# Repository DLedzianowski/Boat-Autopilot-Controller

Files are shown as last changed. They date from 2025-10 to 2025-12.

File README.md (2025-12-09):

# Boat-Autopilot-Controller
PCB for a small boat autopilot system. Collects sensor data and drives actuators to maintain set course/position.

scr2

## Main Features
- STM32WB55 – main MCU with BLE
- MAX-M10S – GNSS positioning
- TMC2208 – stepper motor driver
- LIS3MDL – magnetometer (compass)
- AS5600 connector – absolute encoder input
- DC motor controller connector

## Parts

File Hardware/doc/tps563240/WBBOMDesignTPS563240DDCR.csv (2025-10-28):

Part | Manufacturer | Part Number | Quantity | Price ($) | Footprint (mm²) | Description
Rfbt | Vishay-Dale | CRCW040245K3FKED | 1 | 0.01 | 3 | Resistance: 45.3 kΩ Tolerance: 1.0% Power: 63 mW
Rfbb | Yageo | RC0201FR-0710KL | 1 | 0.01 | 2.08 | Resistance: 10 kΩ Tolerance: 1.0% Power: 50 mW
U1 | Texas Instruments | TPS563240DDCR | 1 | 0.23 | 10.47
L1 | Coilcraft | SER1590-152MLB | 1 | 1.12 | 324.12 | L: 1.5 µH DCR: 1.1 mΩ IDC: 19 A
Cin | MuRata | GRM21BR61E106MA73L | 2 | 0.04 | 6.75 | Cap: 10 µF Total Derated Cap: 2.8 µF VDC: 25 V ESR: 4 mΩ Package: 0805
Cboot | Taiyo Yuden | EMK107B7104KA-T | 1 | 0.01 | 4.68 | Cap: 100 nF Total Derated Cap: 100 nF VDC: 16 V ESR: 1 mΩ Package: 0603
Cout | MuRata | GRM188R60J226MEA0D | 3 | 0.04 | 4.68 | Cap: 22 µF Total Derated Cap: 24 µF VDC: 6.3 V ESR: 1 mΩ Package: 0603
Cinx | Yageo | CC0805KRX7R9BB104 | 1 | 0.02 | 6.75 | Cap: 100 nF Total Derated Cap: 98 nF VDC: 50 V ESR: 1 mΩ Package: 0805

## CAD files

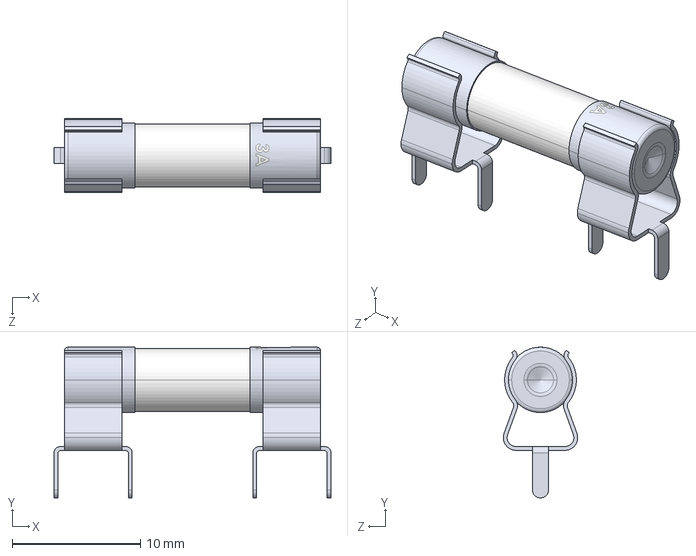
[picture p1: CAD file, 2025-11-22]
Hardware/kicad/PUEiE_pcb/models/Fuse Holder.step
21.6 x 11.8 x 5.80 mm
Fuse Clip x 2
3A Fuse

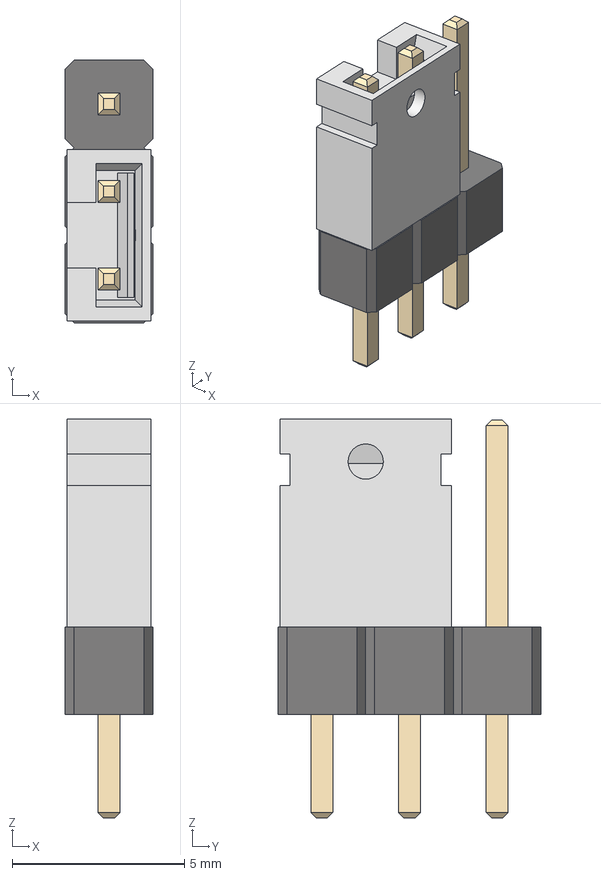
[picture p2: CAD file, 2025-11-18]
Hardware/kicad/PUEiE_pcb/models/pin_jumper_2.54mm.step
2.54 x 7.62 x 11.6 mm
PinHeader_1x03_P254mm_Vertical
26m5017_142270-1

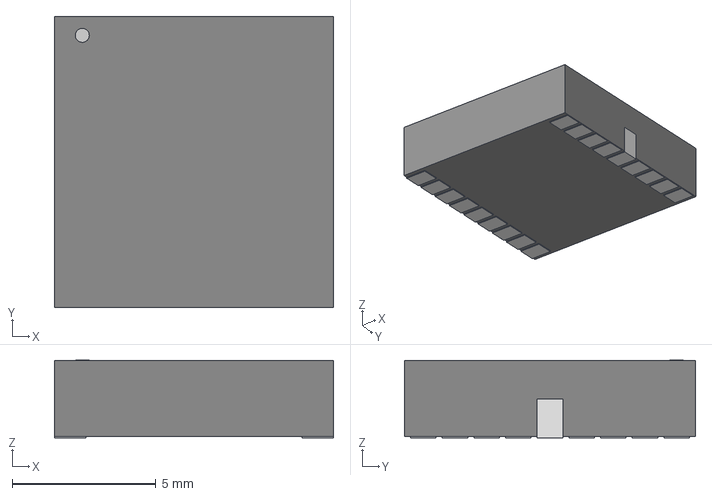
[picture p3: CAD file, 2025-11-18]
Hardware/kicad/PUEiE_pcb/models/MOD18_MAX-M10M_UBL.step
9.70 x 10.1 x 2.69 mm

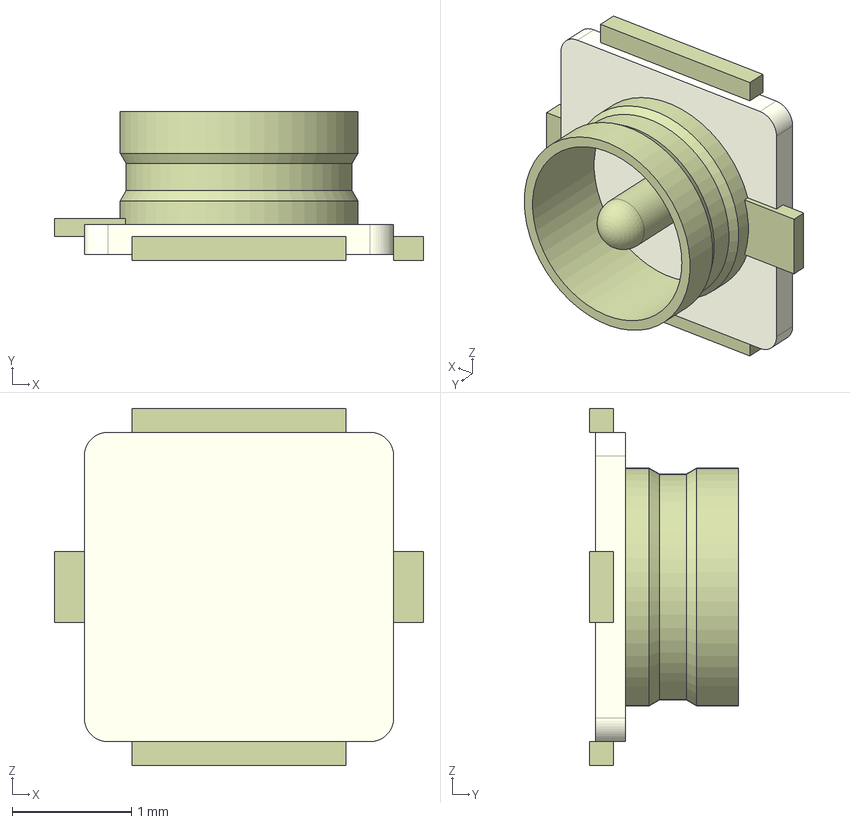
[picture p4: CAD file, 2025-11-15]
Hardware/kicad/PUEiE_pcb/models/ipex_connector.step
3.10 x 1.25 x 3.00 mm

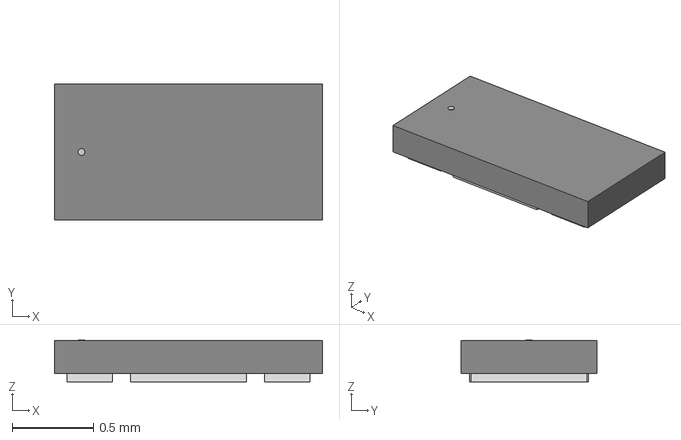
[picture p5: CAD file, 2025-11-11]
Hardware/kicad/PUEiE_pcb/models/DLF162500LT-5028A1.step
1.65 x 0.838 x 0.257 mm

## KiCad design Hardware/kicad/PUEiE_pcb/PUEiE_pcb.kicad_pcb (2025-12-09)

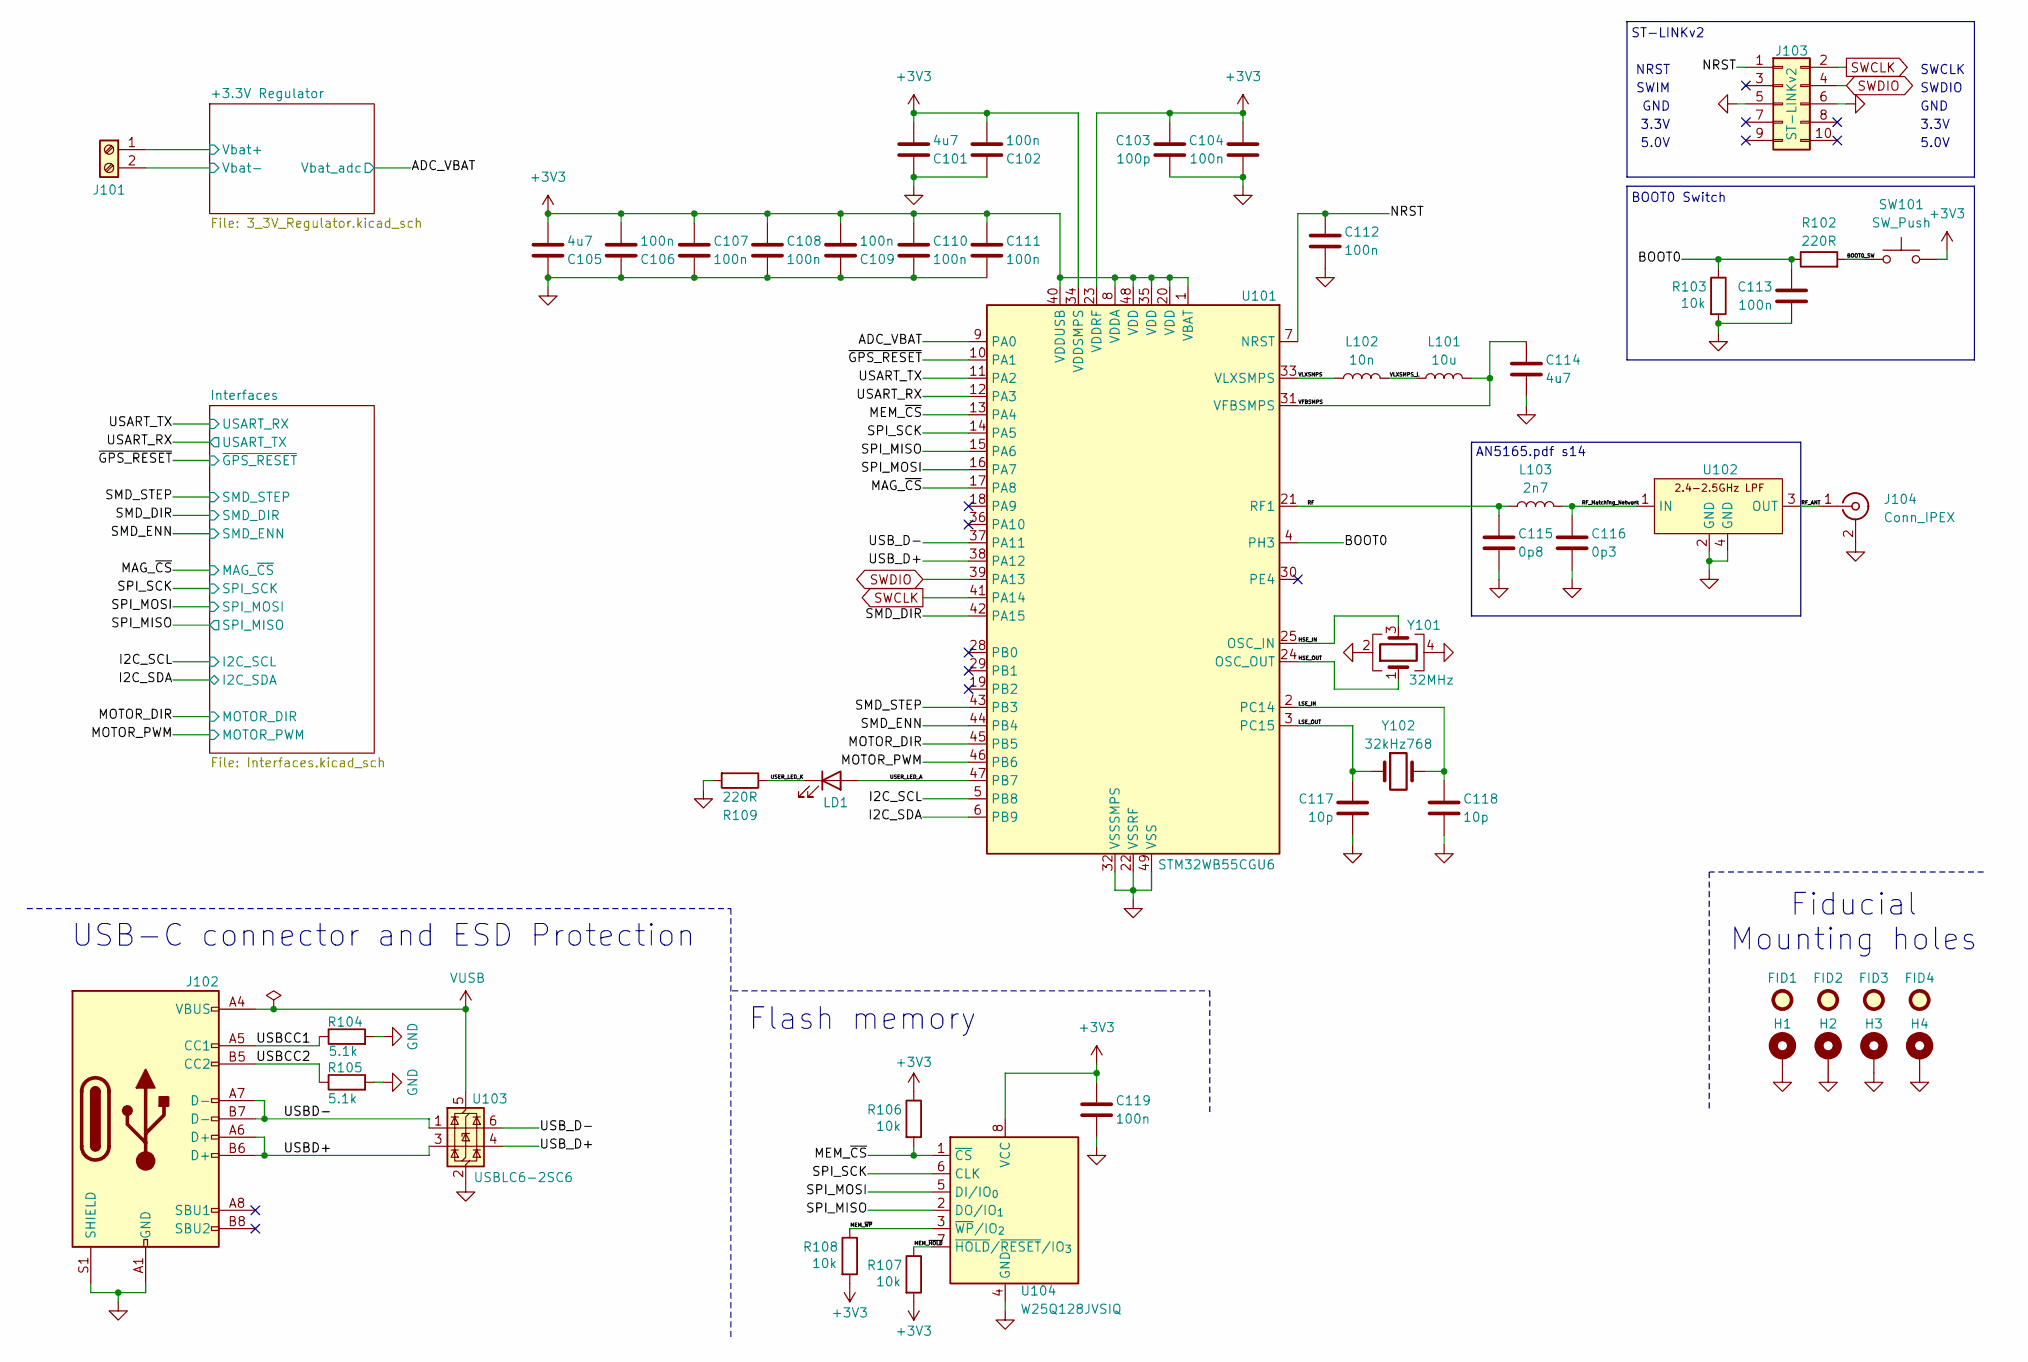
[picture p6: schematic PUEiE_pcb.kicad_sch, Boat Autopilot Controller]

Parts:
C101, C105, C114: 4u7; C_0805_2012Metric; MFR Part CL21A475KAQNNNE
C102, C104, C106, C107, C108, C109, C110, C111, C112, C113, C119: 100n; C_0805_2012Metric; MFR Part CL21B104KCFNNNE
C103: 100p; C_0805_2012Metric; MFR Part CL21C101JBANNNC
C115: 0p8; C_0402_1005Metric; MFR Part GRM1555C1HR80BA01D
C116: 0p3; C_0402_1005Metric; MFR Part GRM1555C1HR30WA01D
C117, C118: 10p; C_0603_1608Metric; MFR Part CL10C100JB8NNNC
FID1, FID2, FID3, FID4: Fiducial; Fiducial_1mm_Mask2mm
H1, H2, H3, H4: MountingHole_Pad; MountingHole_3.2mm_M3_Pad
J101: Screw_Terminal_01x02; TerminalBlock_Phoenix_PT-1,5-2-3.5-H_1x02_P3.50mm_Horizontal; MFR Part PRT-08084
J102: USB_C_Receptacle_USB2.0_16P; USB_C_Receptacle_GCT_USB4105-xx-A_16P_TopMnt_Horizontal; MFR Part USB4105-GF-A-060
J103: ST-LINKv2; PinHeader_2x05_P2.54mm_Vertical; MFR Part HX JN1.27-2x5P ZZ H4.9
J104: Conn_IPEX; IPEX Male; MFR Part BWIPX-1-001E
L101: 10u; L_0603_1608Metric; MFR Part SDFL1608S100KTF
L102: 10n; L_0402_1005Metric; MFR Part LQG15WZ10NJ02D
L103: 2n7; L_0402_1005Metric; MFR Part LQG15HS2N7S02D
LD1: LD1; LED_0805_2012Metric; MFR Part NCD0805B2
R102, R109: 220R; R_0805_2012Metric; MFR Part 0805W8F2200T5E
R103, R106, R107, R108: 10k; R_0805_2012Metric; MFR Part 0805W8F1002T5E
R104, R105: 5.1k; R_0805_2012Metric; MFR Part 0805W8F5101T5E
SW101: SW_Push; SW_2pin_5.5x2.0mm; MFR Part TS-1088-AR02016
U101: STM32WB55CGU6; QFN-48-1EP_7x7mm_P0.5mm_EP5.6x5.6mm_ThermalVias; MFR Part STM32WB55CGU6
U102: DLF162500LT-5028A1; MFR Part DLF162500LT-5028A1
U103: USBLC6-2SC6; SOT-23-6; MFR Part USBLC6-2SC6
U104: W25Q128JVSIQ; SOIC-8_5.3x5.3mm_P1.27mm; MFR Part W25Q128JVSIQ
Y101: 32MHz; Crystal_SMD_2016-4Pin_2.0x1.6mm; MFR Part NX2016SA-32MHZ-STD-CZS-5
Y102: 32kHz768; Crystal_SMD_2012-2Pin_2.0x1.2mm; MFR Part NX2012SA 32.768KHZ STD-MUB-1

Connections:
+3V3: C101.2, C102.2, C103.1, C104.1, C105.2, C106.2, C107.1, C108.1, C109.2, C110.1, C111.1, C119.1, R106.1, R107.2, R108.2, SW101.2, U101.1 (VBAT), U101.8 (VDDA), U101.20 (VDD), U101.23 (VDDRF), U101.34 (VDDSMPS), U101.35 (VDD), U101.40 (VDDUSB), U101.48 (VDD), U104.8 (VCC); also elsewhere on the board
/+3.3V Regulator/Vbat+: J101.1; also elsewhere on the board
/ADC_VBAT: U101.9 (PA0); also elsewhere on the board
/BOOT0: C113.1, R102.1, R103.1, U101.4 (PH3)
/BOOT0_SW: R102.2, SW101.1
/HSE_IN: U101.25 (OSC_IN), Y101.3
/HSE_OUT: U101.24 (OSC_OUT), Y101.1
/I2C_SCL: U101.5 (PB8); also elsewhere on the board
/I2C_SDA: U101.6 (PB9); also elsewhere on the board
/LSE_IN: C118.1, U101.2 (PC14), Y102.2
/LSE_OUT: C117.1, U101.3 (PC15), Y102.1
/MAG_~CS: U101.17 (PA8); also elsewhere on the board
/MEM_~CS: R106.2, U101.13 (PA4), U104.1 (~CS)
/MEM_~HOLD: R107.1, U104.7 (~HOLD/~RESET/IO_{3})
/MEM_~WP: R108.1, U104.3 (~WP/IO_{2})
/MOTOR_DIR: U101.45 (PB5); also elsewhere on the board
/MOTOR_PWM: U101.46 (PB6); also elsewhere on the board
/NRST: C112.1, J103.1, U101.7 (NRST)
/RF: C115.1, L103.1, U101.21 (RF1)
/RF_ANT: J104.1 (In), U102.3 (OUT)
/RF_Matching_Network: C116.1, L103.2, U102.1 (IN)
/SMD_DIR: U101.42 (PA15); also elsewhere on the board
/SMD_ENN: U101.44 (PB4); also elsewhere on the board
/SMD_STEP: U101.43 (PB3); also elsewhere on the board
/SPI_MISO: U101.15 (PA6), U104.2 (DO/IO_{1}); also elsewhere on the board
/SPI_MOSI: U101.16 (PA7), U104.5 (DI/IO_{0}); also elsewhere on the board
/SPI_SCK: U101.14 (PA5), U104.6 (CLK); also elsewhere on the board
/USART_RX: U101.12 (PA3); also elsewhere on the board
/USART_TX: U101.11 (PA2); also elsewhere on the board
/USBCC1: J102.A5 (CC1), R104.1
/USBCC2: J102.B5 (CC2), R105.1
/USBD+: J102.A6 (D+), J102.B6 (D+), U103.3 (I/O2)
/USBD-: J102.A7 (D-), J102.B7 (D-), U103.1 (I/O1)
/USB_D+: U101.38 (PA12), U103.4 (I/O2)
/USB_D-: U101.37 (PA11), U103.6 (I/O1)
/USER_LED_A: LD1.2 (A), U101.47 (PB7)
/USER_LED_K: LD1.1 (K), R109.1
/VFBSMPS: C114.1, L101.2, U101.31 (VFBSMPS)
/VLXSMPS: L102.1, U101.33 (VLXSMPS)
/VLXSMPS_L: L101.1, L102.2
/~GPS_RESET: U101.10 (PA1); also elsewhere on the board
GND: C101.1, C102.1, C103.2, C104.2, C105.1, C106.1, C107.2, C108.2, C109.1, C110.2, C111.2, C112.2, C113.2, C114.2, C115.2, C116.2, C117.2, C118.2, C119.2, H1.1, H2.1, H3.1, H4.1, J101.2, J102.A1 (GND), J102.A12 (GND), J102.B1 (GND), J102.B12 (GND), J102.S1 (SHIELD), J103.5, J103.6, J104.2 (Ext), R103.2, R104.2, R105.2, R109.2, U101.22 (VSSRF), U101.32 (VSSSMPS), U101.49 (VSS), U102.2 (GND), U102.4 (GND), U103.2 (GND), U104.4 (GND), Y101.2, Y101.4; also elsewhere on the board
SWCLK: J103.2, U101.41 (PA14)
SWDIO: J103.4, U101.39 (PA13)
VUSB: J102.A4 (VBUS), J102.A9 (VBUS), J102.B4 (VBUS), J102.B9 (VBUS), U103.5 (VBUS); also elsewhere on the board

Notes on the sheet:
AN5165.pdf s14
5.0V
BOOT0 Switch
GND
USB-C connector and ESD Protection
3.3V
SWDIO
SWCLK
ST-LINKv2
Fiducial Mounting holes
SWIM
Flash memory
NRST

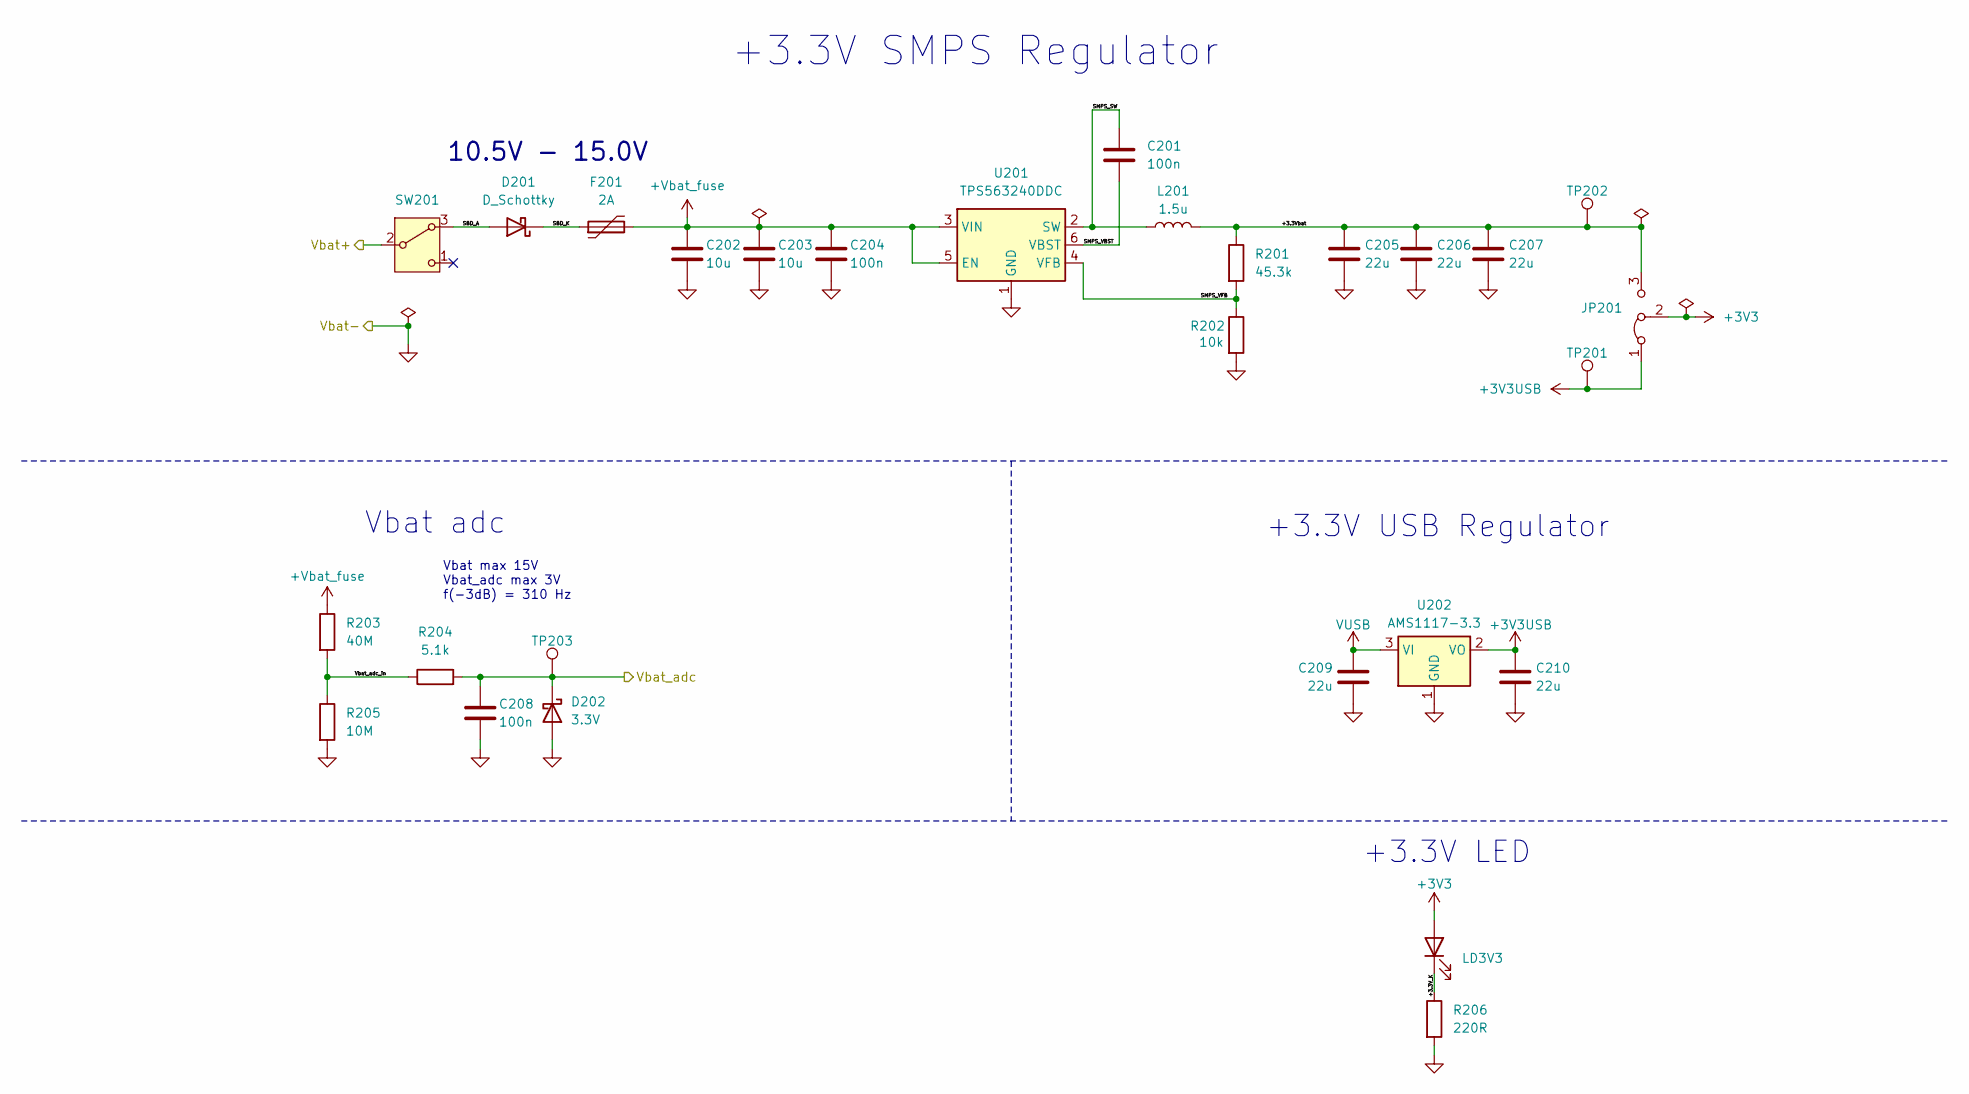
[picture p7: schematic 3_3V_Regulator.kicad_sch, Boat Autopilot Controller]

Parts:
C201: 100n; C_0603_1608Metric; MFR Part EMK107B7104KA-T
C202, C203: 10u; C_0805_2012Metric; MFR Part GRM21BR61E106MA73L
C204, C208: 100n; C_0805_2012Metric; MFR Part CL21B104KCFNNNE
C205, C206, C207, C209, C210: 22u; C_0603_1608Metric; MFR Part GRM188R60J226MEA0D
D201: D_Schottky; D_SMA; MFR Part SS34
D202: 3.3V; D_SOD-323; MFR Part MMSZ5226BS-7-F
F201: 2A; Fuseholder_Clip-5x20mm_Littelfuse_111_Inline_P20.00x5.00mm_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; MFR Part 5x20 环保 保险管夹/座
JP201: Jumper_3_Bridged12; PinHeader_1x03_P2.54mm_Vertical
L201: 1.5u; L_Sunlord_MWSA1005S; MFR Part 104CDMCCDS-1R5MC
LD3V3: +3.3V; LED_0805_2012Metric; MFR Part NCD0805R1
R201: 45.3k; R_0805_2012Metric; MFR Part 0805W8F4532T5E
R202: 10k; R_0805_2012Metric; MFR Part 0805W8F1002T5E
R203: 40M; R_0805_2012Metric; MFR Part RH73H2A40MKTN
R204: 5.1k; R_0805_2012Metric; MFR Part 0805W8F5101T5E
R205: 10M; R_0805_2012Metric; MFR Part 0805W8F1005T5E
R206: 220R; R_0805_2012Metric; MFR Part 0805W8F2200T5E
SW201: SW_Nidec_CAS-120A1; PinHeader_1x03_P2.54mm_Vertical; MFR Part TS01CBE
TP201, TP202, TP203: TestPoint; TestPoint_Pad_D2.0mm
U201: TPS563240DDC; SOT-23-6; MFR Part TPS563240DDCR
U202: AMS1117-3.3; SOT-223-3_TabPin2; MFR Part AMS1117-3.3

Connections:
+3V3: JP201.2 (C), LD3V3.2 (A); also elsewhere on the board
+3V3USB: C210.1, JP201.1 (A), TP201.1, U202.2 (VO)
+Vbat_fuse: C202.1, C203.1, C204.1, F201.2, R203.1, U201.3 (VIN), U201.5 (EN); also elsewhere on the board
/+3.3V Regulator/+3.3V_K: LD3V3.1 (K), R206.1
/+3.3V Regulator/+3.3Vbat: C205.1, C206.1, C207.1, JP201.3 (B), L201.2, R201.1, TP202.1
/+3.3V Regulator/SBD_A: D201.2 (A), SW201.3 (A)
/+3.3V Regulator/SBD_K: D201.1 (K), F201.1
/+3.3V Regulator/SMPS_SW: C201.1, L201.1, U201.2 (SW)
/+3.3V Regulator/SMPS_VBST: C201.2, U201.6 (VBST)
/+3.3V Regulator/SMPS_VFB: R201.2, R202.1, U201.4 (VFB)
/+3.3V Regulator/Vbat+: SW201.2 (B); also elsewhere on the board
/+3.3V Regulator/Vbat_adc_in: R203.2, R204.1, R205.1
/ADC_VBAT: C208.1, D202.1 (K), R204.2, TP203.1; also elsewhere on the board
GND: C202.2, C203.2, C204.2, C205.2, C206.2, C207.2, C208.2, C209.2, C210.2, D202.2 (A), R202.2, R205.2, R206.2, U201.1 (GND), U202.1 (GND); also elsewhere on the board
VUSB: C209.1, U202.3 (VI); also elsewhere on the board

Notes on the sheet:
Vbat adc
+3.3V SMPS Regulator
Vbat max 15V Vbat_adc max 3V f(-3dB) = 310 Hz
+3.3V USB Regulator
+3.3V LED
10.5V - 15.0V

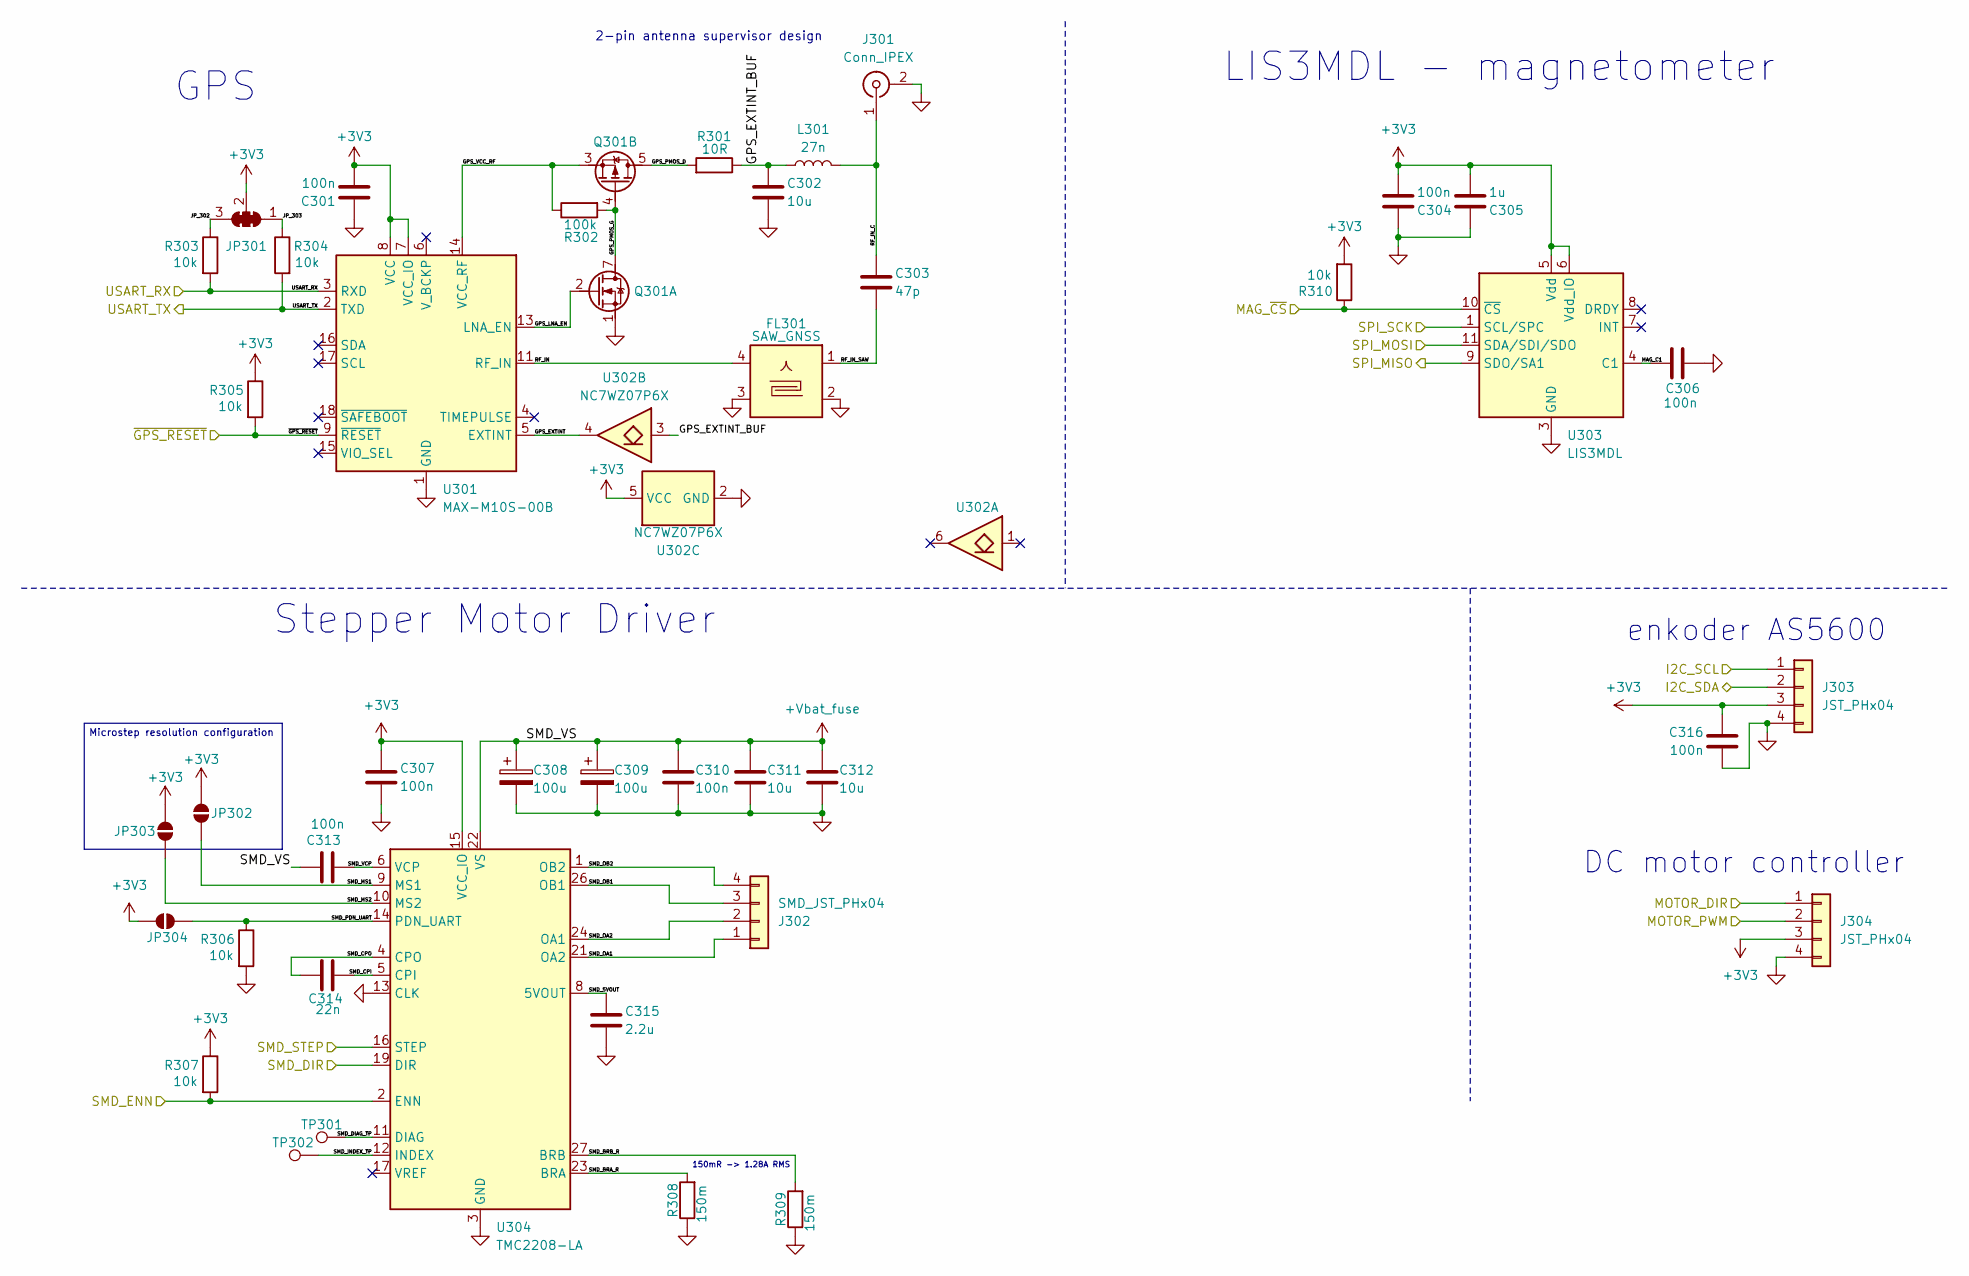
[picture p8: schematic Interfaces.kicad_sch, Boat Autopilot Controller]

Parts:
C301, C304, C306, C307, C310, C313, C316: 100n; C_0805_2012Metric; MFR Part CL21B104KCFNNNE
C302: 10u; C_0805_2012Metric; MFR Part CL21B103KBANNNC
C303: 47p; C_0805_2012Metric; MFR Part C2012C0G1H470JT000N
C305: 1u; C_0805_2012Metric; MFR Part CL21B105KBFNNNE
C308, C309: 100u; CP_Elec_6.3x7.7; MFR Part RVT1E101M0607
C311, C312: 10u; C_1206_3216Metric; MFR Part CL31A106KBHNNNE
C314: 22n; C_0805_2012Metric; MFR Part CL21B104KCFNNNE
C315: 2.2u; C_0805_2012Metric; MFR Part CL21A225KBQNNNE
FL301: SAW_GNSS; Filter_1109-5_1.1x0.9mm; MFR Part SAFFB1G56KB0F0AR1X
J301: Conn_IPEX; IPEX Male; MFR Part BWIPX-1-001E
J302: SMD_JST_PHx04; JST_XH_S4B-XH-A_1x04_P2.50mm_Horizontal; MFR Part S4B-XH-A-1
J303, J304: JST_PHx04; JST_XH_S4B-XH-A_1x04_P2.50mm_Horizontal; MFR Part S4B-XH-A-1
JP301: SolderJumper_3_Bridged123; SolderJumper-3_P2.0mm_Open_TrianglePad1.0x1.5mm
JP302, JP303, JP304: SolderJumper_2_Open; SolderJumper-2_P1.3mm_Open_TrianglePad1.0x1.5mm
L301: 27n; L_0402_1005Metric; MFR Part LQG15HS27NJ02D
Q301: ZXMC4559DN8TA; SOP-8_3.76x4.96mm_P1.27mm; MFR Part ZXMC4559DN8TA
R301: 10R; R_0603_1608Metric; MFR Part ERJUP3J100V
R302: 100k; R_0603_1608Metric; MFR Part 0603WAF1003T5E
R303, R304, R305, R306, R307, R310: 10k; R_0805_2012Metric; MFR Part 0805W8F1002T5E
R308, R309: 150m; R_1206_3216Metric; MFR Part 1206W4F150LT5E
TP301, TP302: TestPoint; TestPoint_Pad_D2.0mm
U301: MAX-M10S-00B; ublox_MAX; MFR Part MAX-M10S-00B
U302: NC7WZ07P6X; SOT-363_SC-70-6; MFR Part NC7WZ07P6X
U303: LIS3MDL; LGA-12_2x2mm_P0.5mm; MFR Part LIS3MDLTR
U304: TMC2208-LA; QFN-28-1EP_5x5mm_P0.5mm_EP3.75x3.75mm_ThermalVias; MFR Part TMC2208-LA-T

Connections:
+3V3: C301.2, C304.2, C305.2, C307.1, C316.1, J303.3, J304.3, JP301.2 (C), JP302.1 (A), JP303.1 (A), JP304.2 (B), R305.1, R307.1, R310.2, U301.7 (VCC_IO), U301.8 (VCC), U302.5 (VCC), U303.5 (Vdd), U303.6 (Vdd_IO), U304.15 (VCC_IO); also elsewhere on the board
+Vbat_fuse: C308.1, C309.1, C310.1, C311.1, C312.1, C313.1, U304.22 (VS), U304.28 (VS); also elsewhere on the board
/I2C_SCL: J303.1; also elsewhere on the board
/I2C_SDA: J303.2; also elsewhere on the board
/Interfaces/GPS_EXTINT: U301.5 (EXTINT), U302.4
/Interfaces/GPS_EXTINT_BUF: C302.1, L301.1, R301.1, U302.3
/Interfaces/GPS_LNA_EN: Q301.2 (G1), U301.13 (LNA_EN)
/Interfaces/GPS_PMOS_D: Q301.5 (D2), Q301.6 (D1), R301.2
/Interfaces/GPS_PMOS_G: Q301.4 (G2), Q301.7 (D1), Q301.8 (D1), R302.2
/Interfaces/GPS_VCC_RF: Q301.3 (S2), R302.1, U301.14 (VCC_RF)
/Interfaces/JP_302: JP301.3 (B), R303.1
/Interfaces/JP_303: JP301.1 (A), R304.1
/Interfaces/MAG_C1: C306.2, U303.4 (C1)
/Interfaces/RF_IN: FL301.4, U301.11 (RF_IN)
/Interfaces/RF_IN_C: C303.1, J301.1 (In), L301.2
/Interfaces/RF_IN_SAW: C303.2, FL301.1
/Interfaces/SMD_5VOUT: C315.1, U304.8 (5VOUT)
/Interfaces/SMD_BRA_R: R308.2, U304.23 (BRA)
/Interfaces/SMD_BRB_R: R309.2, U304.27 (BRB)
/Interfaces/SMD_CPI: C314.1, U304.5 (CPI)
/Interfaces/SMD_CPO: C314.2, U304.4 (CPO)
/Interfaces/SMD_DIAG_TP: TP301.1, U304.11 (DIAG)
/Interfaces/SMD_INDEX_TP: TP302.1, U304.12 (INDEX)
/Interfaces/SMD_MS1: JP302.2 (B), U304.9 (MS1)
/Interfaces/SMD_MS2: JP303.2 (B), U304.10 (MS2)
/Interfaces/SMD_OA1: J302.1, U304.21 (OA2)
/Interfaces/SMD_OA2: J302.2, U304.24 (OA1)
/Interfaces/SMD_OB1: J302.3, U304.26 (OB1)
/Interfaces/SMD_OB2: J302.4, U304.1 (OB2)
/Interfaces/SMD_PDN_UART: JP304.1 (A), R306.1, U304.14 (PDN_UART)
/Interfaces/SMD_VCP: C313.2, U304.6 (VCP)
/MAG_~CS: R310.1, U303.10 (~CS); also elsewhere on the board
/MOTOR_DIR: J304.1; also elsewhere on the board
/MOTOR_PWM: J304.2; also elsewhere on the board
/SMD_DIR: U304.19 (DIR); also elsewhere on the board
/SMD_ENN: R307.2, U304.2 (ENN); also elsewhere on the board
/SMD_STEP: U304.16 (STEP); also elsewhere on the board
/SPI_MISO: U303.9 (SDO/SA1); also elsewhere on the board
/SPI_MOSI: U303.11 (SDA/SDI/SDO); also elsewhere on the board
/SPI_SCK: U303.1 (SCL/SPC); also elsewhere on the board
/USART_RX: R304.2, U301.2 (TXD); also elsewhere on the board
/USART_TX: R303.2, U301.3 (RXD); also elsewhere on the board
/~GPS_RESET: R305.2, U301.9 (~RESET); also elsewhere on the board
GND: C301.1, C302.2, C304.1, C305.1, C306.1, C307.2, C308.2, C309.2, C310.2, C311.2, C312.2, C315.2, C316.2, FL301.2, FL301.3, FL301.5, J301.2 (Ext), J303.4, J304.4, Q301.1 (S1), R306.2, R308.1, R309.1, U301.1 (GND), U301.10 (GND), U301.12 (GND), U302.2 (GND), U303.2 (GND), U303.3 (GND), U303.12 (GND), U304.3 (GND), U304.13 (CLK), U304.18 (GND), U304.29 (GND); also elsewhere on the board

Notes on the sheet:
GPS
enkoder AS5600
2-pin antenna supervisor design
DC motor controller
Stepper Motor Driver
LIS3MDL - magnetometer
Microstep resolution configuration
150mR -> 1.28A RMS

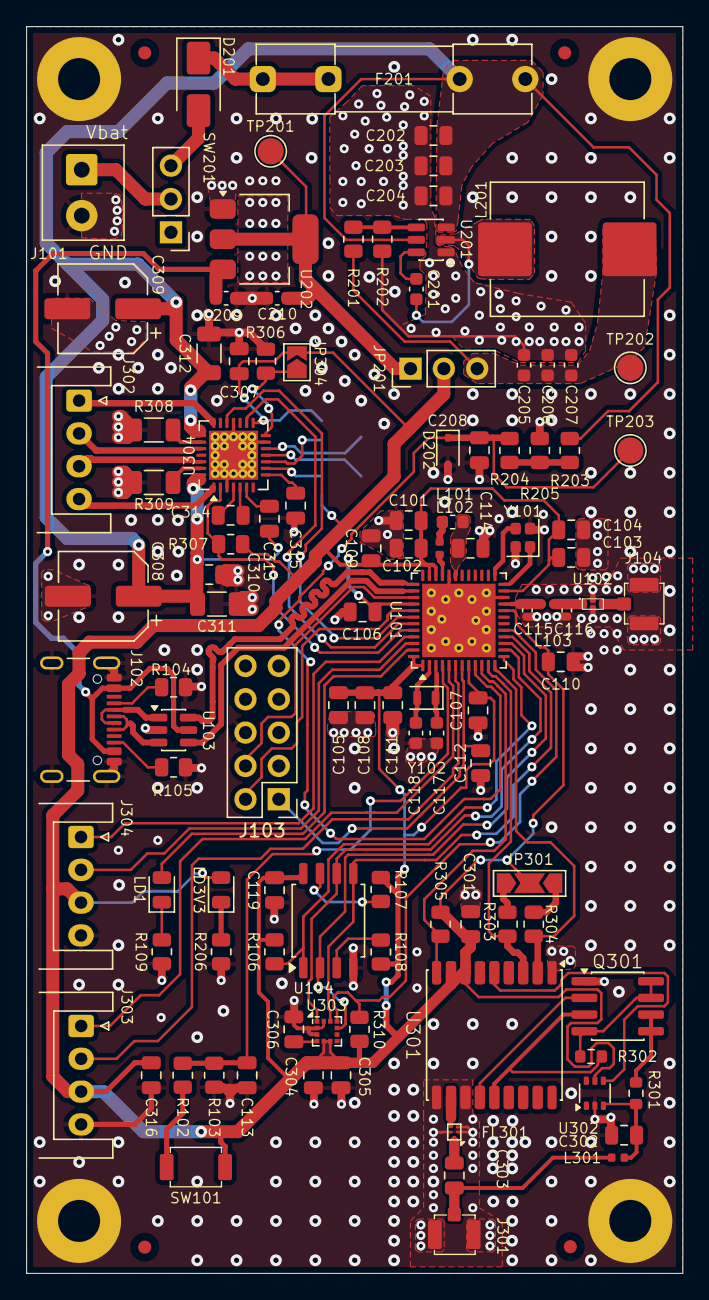
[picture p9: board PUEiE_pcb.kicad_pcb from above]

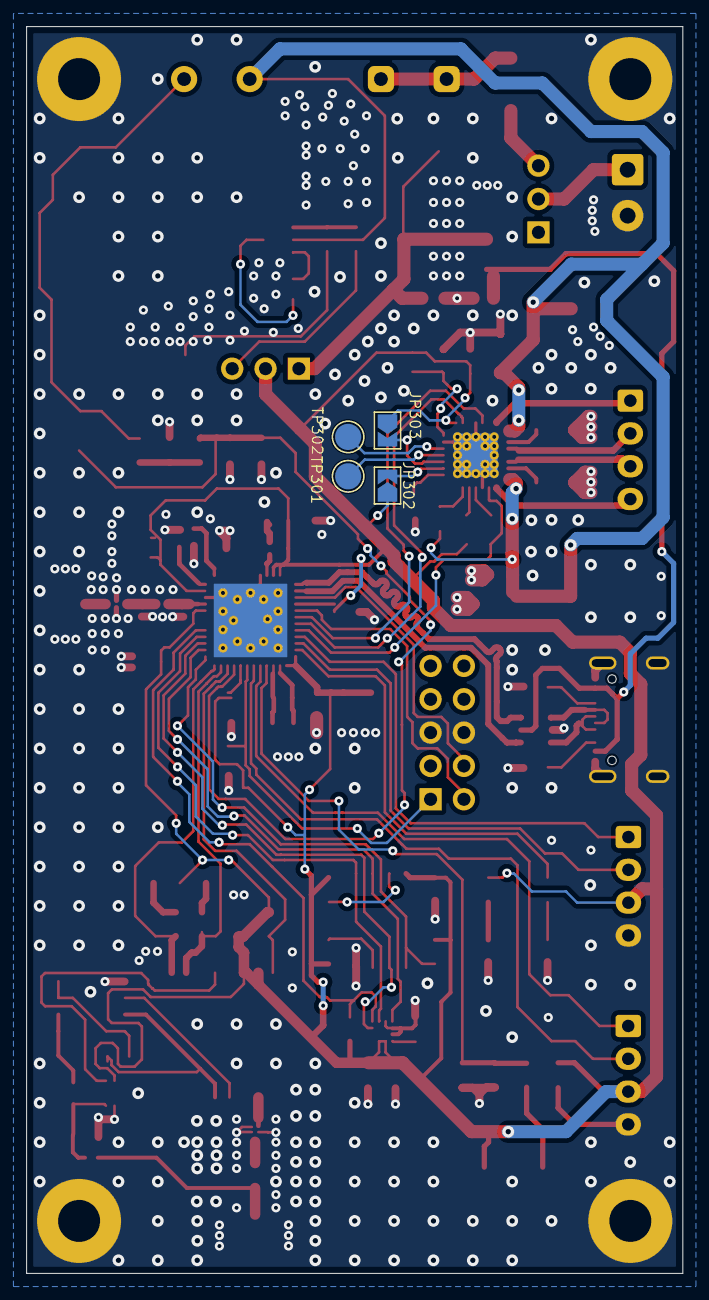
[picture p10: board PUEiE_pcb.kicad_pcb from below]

Board: 2 copper layers, 50.0 x 95.0 mm, 121 parts (4 on the bottom side), 82 nets.

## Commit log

2025-10-28 tps563240, GNSS
    [PUEiE_pcb.kicad_sch, WBBOMDesignTPS563240DDCR.csv]
2025-11-04 magnetometer ,stepper controller
    [Interfaces.kicad_sch, PUEiE_pcb.kicad_sch]
2025-11-15 All Schematics
    [3_3V_Regulator.kicad_sch, PUEiE_pcb.kicad_sch, ipex_connector.step]
2025-11-16 Board Setup
    [3_3V_Regulator.kicad_sch, Interfaces.kicad_sch, PUEiE_pcb.kicad_pcb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]
2025-11-18 pcb placement
    [3_3V_Regulator.kicad_sch, DLF162500LT-5028A1.step, Interfaces.kicad_sch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]
2025-11-21 PCB layout
    [3_3V_Regulator.kicad_sch, Interfaces.kicad_sch, PUEiE_pcb.kicad_pcb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]
2025-11-22 Final PCB layout
    [Fuse Holder.step, PUEiE_pcb.kicad_pcb, PUEiE_pcb.kicad_sch]
2025-12-09 Final PCB design
    [3_3V_Regulator.kicad_sch, Interfaces.kicad_sch, PUEiE_pcb.kicad_pcb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]
